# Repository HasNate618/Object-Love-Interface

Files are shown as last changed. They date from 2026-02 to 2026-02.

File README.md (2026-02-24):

# Object-Love-Interface 💘

> **🥇 Best Useless Hack** — CTRL+HACK+DEL 2.0 (York University)

What if you could go on a date with... literally any object?

Place an object in front of the camera. OLI scans it. Suddenly your bowl of ramen has a personality, a voice, opinions, and emotional availability. Using **Google Gemini API** to generate personalities and **ElevenLabs** to give them voices, we turned random objects into emotionally available Valentine's dates—all running on **Raspberry Pi** plus **three different ESP32 devices**.

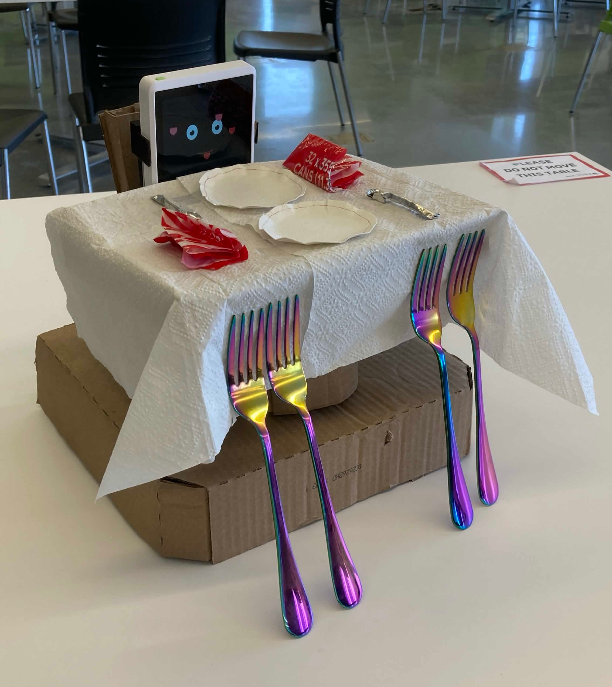
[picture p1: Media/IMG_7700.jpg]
Physical OLI Device


---

## 🏗️ System Architecture

A sophisticated multi-device IoT system bridging:
- **AI Generation** (Google Gemini 2.0 Flash) — personality description from image
- **Speech Synthesis** (ElevenLabs) — voices with emotion and character
- **Real-Time Display Sync** — synchronized animations across heterogeneous hardware

### Hardware Stack
| Device | Purpose | Interface | MCU |
|---|---|---|-----|
| **SenseCAP Indicator D1101** | Display + haptic feedback | USB Serial (921600 baud) | ESP32-S3 + RP2040 |
| **M5Stack Core** | WiFi audio speaker | HTTP (port 8082) | ESP32 |
| **Raspberry Pi 4/5** | Orchestrator brain | GPIO, USB, WiFi | ARM Cortex-A72 |
| **Brio Webcam** | Video + microphone input | USB | — |
| **Servo Motor** | Physical expression | GPIO serial | — |

### Software Stack

**Backend (Python 2440 LOC)**
- **OpenCV** — webcam capture (30 FPS video streaming)
- **PySerial** — USB serial protocol for SenseCAP (JPEG transfer, command/response)
- **PyAudio** — microphone input & voice recording
- **requests** — HTTP orchestration to Node.js server
- **google-generativeai** — Gemini API (personality generation)
- **pydub** — audio encoding/transcoding

**Frontend/Server (Node.js)**
- **Express.js** — HTTP API server (:3000)
- **@google/generative-ai** — Gemini 2.0 Flash for text generation
- **@elevenlabs/elevenlabs-js** — TTS voice synthesis with emotion
- **WebSocket (ws)** — real-time communication
- **multer** — file upload handling
- **dotenv** — environment secrets management

**Firmware (PlatformIO)**
- **ESP32-S3** — RGB LCD driver (ST7701S), JPEG decoding, touch input
- **RP2040** — buzzer control via UART, melody synthesis
- **ESP32** (M5Stack) — WiFi stack, ESP8266Audio library, internal DAC

---

## 🔄 Core Data Flow

### Image → Personality → Synchronized Playback (5-15s)

```
┌─ Webcam Frame (OpenCV, 30 FPS)
│
├─ Encode JPEG (Pillow)
│  └─ Send to SenseCAP display (USB serial, 921600 baud)
│
├─ Draw UI overlay (pink "Date ♥" button)
│
├─ Wait for button press (GPIO17 interrupt or SenseCAP touch)
│
├─ On trigger:
│  ├─ Save frame to disk
│  │
│  ├─ POST to Node.js: /generate-personality {image_b64}
│  │  └─ Google Gemini API (2-5s)
│  │     └─ Generate personality text + voice selection
│  │
│  ├─ ElevenLabs TTS synthesis (3-8s)
│  │  └─ Generate MP3 with emotion/character
│  │
│  ├─ Send face JPEG to SenseCAP (serial)
│  │
│  ├─ POST to M5Stack: /play {audio_url}
│  │  └─ M5 fetches MP3 via WiFi HTTP GET
│  │
│  ├─ mouth_sync.py: Poll M5 /status every 16ms
│  │  └─ Map audio position → mouth shape keyframe (0-8 frames)
│  │  └─ Resend JPEG with updated mouth to SenseCAP
│  │  └─ Stop at ~70% duration (character reaction)
│  │
│  └─ Return to video feed
```

### Voice Conversation Loop

```
Button Held (GPIO18 interrupt)
    ↓
Record microphone audio (PyAudio, 16-bit PCM @ device rate)
    ↓
Button Released
    ↓
Encode WAV → MP3 (pydub)
    ↓
POST to Node.js: /respond {audio_b64, context}
    ↓
Node:
  • Google Cloud Speech-to-Text (transcription)
  • Gemini API (contextual response using conversation history)
  • ElevenLabs TTS (emotion-aware voice synthesis)
  ↓
Python:
  • Fetch MP3 URL from response
  • POST to M5Stack: /play {audio_url}
  • mouth_sync.py: Sync mouth animation with audio
  • Update conversation context
  ↓
Return to video feed (ready for next interaction)
```

---

## 📁 Project Structure

```
Object-Love-Interface/
├── README.md (this file)
├── plan-rpiMigration.md          # Windows → Raspberry Pi migration guide
├── demo_script.md                # Demonstration walkthrough
│
├── Screen/                        # SenseCAP Indicator (ESP32-S3 + RP2040)
│   ├── esp32s3_firmware/         # PlatformIO: LCD driver + JPEG decoder
│   ├── rp2040_firmware/          # PlatformIO: Buzzer + melody control
│   └── controller/               # Python serial protocol library
│       ├── sensecap_controller.py  # Full serial API
│       ├── test_display.py        # RGB test pattern
│       ├── test_image.py          # JPEG encoding test
│       └── quick_test.py          # Integration test
│
├── Audio/                         # M5Stack Core (ESP32 WiFi Speaker)
│   ├── m5core2_firmware/         # PlatformIO: WiFi + audio DAC
│   │   ├── platformio.ini
│   │   └── src/main.cpp          # HTTP API + ESP8266Audio
│   └── README.md                 # HTTP API documentation
│
├── pipeline/                      # Main orchestrator (2440 LOC Python)
│   ├── date_pipeline.py          # (672 L) Video feed → button → personality
│   ├── conversation.py           # (495 L) Voice recording + AI responses
│   ├── mouth_sync.py             # (334 L) Audio position → mouth animation
│   ├── orchestrator.py           # (273 L) Multi-module coordination
│   ├── audio_server.py           # (189 L) Flask HTTP server
│   ├── gpio_button.py            # (140 L) GPIO interrupt handling
│   ├── wifi_link.py              # (215 L) WiFi TCP client for SenseCAP
│   ├── servo_serial.py           # (86 L) Servo motor control
│   ├── requirements.txt           # pip dependencies
│   └── README.md
│
├── image_to_voice/               # Node.js AI + TTS server
│   ├── index.js                  # Express server + Gemini + ElevenLabs
│   ├── package.json              # npm dependencies (express, generative-ai, elevenlabs)
│   ├── .env                      # API keys (gitignored)
│   ├── tmp/                      # Generated MP3 files (served over HTTP)
│   └── helper/                   # State management
│       ├── personality.js        # Personality persistence
│       ├── context.js            # Conversation history (multi-turn)
│       ├── interest.js           # Interest tracking
│       ├── voice.js              # Voice variant selection
│       └── dateStats.js          # Date interaction statistics
│
├── Media/                         # Test media files
│   └── IMG_7700.jpg              # Physical device photo
├── CAD/                           # Hardware designs
└── esp32_main/                   # Legacy ESP32 firmware
```

---

## ⚙️ Technical Implementation Details

### Serial Protocol (SenseCAP ↔ Raspberry Pi)

**Baud Rate**: 921600 (optimized for JPEG throughput)

**Command Format**: JSON-terminated newline, UTF-8 encoded

```json
// Image transfer (3-step handshake)
{"cmd":"image","len":65536}        // Announce size
[wait: {"status":"ready"}]         // Device ready
[send 65536 raw JPEG bytes]        // Binary image data
[wait: {"status":"ok"}]            // Transfer complete

// Buzzer control
{"cmd":"tone","freq":1000,"dur":500}        // Single tone
{"cmd":"melody","notes":"440:200,554:200"}  // Comma-separated freq:duration

// Display control
{"cmd":"clear","color":"#FF00FF"}   // Fill background
{"cmd":"bl","on":true}              // Backlight control
```

### HTTP API (Node.js Server)

**Base URL**: `http://<HOST_IP>:3000`

| Endpoint | Method | Input | Output | Latency |
|---|---|---|---|---|
| `/generate-personality` | POST | `{image_b64, camera_index}` | `{personality, voice_id, interest}` | 2-5s (Gemini) |
| `/respond` | POST | `{transcription, context}` | `{response, audio_url}` | 3-8s (TTS) |
| `/tmp/<filename>.mp3` | GET | — | MP3 audio stream | 0ms (file) |
| `/status` | GET | — | `{personality, voices, context_len}` | 0ms |

### Gemini API Integration

**Model**: `gemini-2.0-flash`

**Prompting Strategy**:
- Image base64 encoded + sent as multipart MIME
- System prompt establishes personality type
- Conversation context appended for multi-turn coherence
- Retry logic with exponential backoff (for 429 rate limits)

```javascript
// Example flow
const prompt = [
  {text: "You are a flirty object with opinions."},
  {inlineData: {mimeType: "image/jpeg", data: imageB64}},
  {text: "Describe yourself in 1-2 sentences."}
];
const response = await model.generateContent(prompt);
```

### ElevenLabs TTS Configuration

**Voice Model**: `elevenlabs-js` library

**Parameters**:
- Model: `eleven_turbo_v2` (fast, 500ms synthesis)
- Stability: 0.5 (balanced personality)
- Similarity boost: 0.75 (character consistency)
- Output format: MP3, 192 kbps

```javascript
const audio = await elevenlabs.generate({
  text: personality_description,
  voice_id: selected_voice,
  model_id: "eleven_turbo_v2"
});
```

### Mouth Sync Algorithm

**Keyframe System**: 9 mouth shapes (0-8 sprites)

**Timing**: Poll M5 `/status` at 16ms intervals (60 FPS target)

```python
# mouth_sync.py logic
audio_position_ms = elapsed_time * 1000
audio_duration_ms = total_duration * 1000

# Stop at 70% for reaction time
cutoff_position = audio_duration_ms * 0.7

mouth_frame = 0
if audio_position_ms < cutoff_position:
    # Map position to mouth shape (0-8)
    mouth_frame = int((audio_position_ms / cutoff_position) * 8)

# Resend JPEG with updated mouth to SenseCAP
send_face_jpeg(mouth_frame)
```

### GPIO Interrupt Handling

**GPIO Pins** (Raspberry Pi):
- **GPIO17**: Date button (primary)
- **GPIO18**: Voice recording (optional)
- **GPIO38**: Limit switch (emergency restart)

**Edge Detection**: Rising edge + debounce (10ms)

```python
# gpio_button.py
def setup_button(pin, callback):
    GPIO.setmode(GPIO.BCM)
    GPIO.setup(pin, GPIO.IN, pull_up_down=GPIO.PUD_UP)
    GPIO.add_event_detect(pin, GPIO.RISING, 
                         callback=callback, bouncetime=10)
```

### Camera Detection (RPi USB)

**Supported**: 
- USB cameras (via `/dev/video*`)
- CSI ribbon cameras
- Brio webcam (UVC)

**Detection**:
```bash
# v4l2 enumeration
v4l2-ctl --list-devices

# OpenCV fallback (auto-select index 0-5)
python find_camera.py
```

---

## 🚀 Quick Start

### Prerequisites
- **Raspberry Pi 4/5** (or Windows laptop for testing)
- **Node.js 18+**
- **Python 3.8+**
- **PlatformIO CLI** (for firmware flashing)
- **ffmpeg** (audio transcoding)

### Setup

```bash
# 1. Clone and install dependencies
git clone https://github.com/HasNate618/Object-Love-Interface.git
cd Object-Love-Interface

# 2. Python environment
pip install -r pipeline/requirements.txt

# 3. Node environment
cd image_to_voice
npm install
cp .env.example .env  # Add GEMINI_API_KEY, ELEVENLABS_API_KEY
cd ..

# 4. Flash firmware (first time only)
cd Screen/esp32s3_firmware && pio run --target upload && cd ../..
cd Screen/rp2040_firmware && pio run --target upload && cd ../..
cd Audio/m5core2_firmware && pio run --target upload && cd ../..

# 5. Update .env for your network
# Edit image_to_voice/.env: set HOST_IP to your RPi IP
# Edit pipeline/config: set SENSECAP_PORT to /dev/ttyUSB0 (RPi) or COM6 (Windows)

# 6. Start services
# Terminal 1:
cd image_to_voice && npm start

# Terminal 2:
cd pipeline && python date_pipeline.py --port /dev/ttyUSB0 --camera 0
```

### Testing Individual Components

```bash
# Test webcam detection
python find_camera.py

# Test SenseCAP serial communication
cd Screen/controller && python test_image.py /dev/ttyUSB0

# Test M5Stack WiFi playback
python test_backends.py

# Test full integration
python pipeline/date_pipeline.py --verbose
```

---

## 🔧 Configuration

### Environment Variables (`.env`)

```bash
# API Keys (REQUIRED)
GEMINI_API_KEY="..."
ELEVENLABS_API_KEY="..."

# Network (UPDATE FOR YOUR SETUP)
HOST_IP=10.216.64.XXX           # Raspberry Pi LAN address
M5CORE2_URL=http://10.216.64.147:8082/play
M5_PLAY_URL=http://10.216.64.147:8082/play

# Server
IMAGE_TO_VOICE_URL=http://localhost:3000
PORT=3000

# Optional
DISABLE_ROBOT_TTS=0
MIC_NAME="Brio"
DATE_CAMERA_INDEX=0
```

---

## 📊 Performance Metrics

| Operation | Duration | Bottleneck |
|---|---|---|
| Webcam capture + JPEG encode | 80-150ms | PIL libjpeg-turbo |
| Gemini API call | 2-5s | Network + model inference |
| ElevenLabs TTS | 3-8s | API latency |
| USB serial JPEG transfer (65KB) | 200-500ms | 921600 baud (~115 KB/s) |
| Mouth sync loop | 16ms/frame | HTTP polling to M5 |
| **Full interaction cycle** (button→speech) | **5-15s** | Gemini + ElevenLabs |

---

## 🛠️ Migration Guide

See [plan-rpiMigration.md](plan-rpiMigration.md) for detailed steps to migrate from Windows laptop to Raspberry Pi, including:
- Serial port remapping (COM6 → `/dev/ttyUSB0`)
- Network configuration (HOST_IP in `.env`)
- Hardware USB reallocation
- Troubleshooting common issues

---

## 🏆 Project Origins

**Built at**: CTRL+HACK+DEL 2.0 (York University Hackathon)  
**Duration**: 36 hours  
**Team**: 3 developers  
**Award**: 🥇 Best Useless Hack  
**Prize**: Iridescent forks (now displayed proudly)

This project perfectly demonstrates the power of combining cutting-edge APIs (Gemini, ElevenLabs) with embedded systems (Raspberry Pi, ESP32 ecosystem) to create something simultaneously useless and technically impressive.

---

## 📚 Further Reading

- [SenseCAP Indicator Hardware](Screen/README.md) — Display firmware + serial protocol
- [M5Stack Audio Server](Audio/README.md) — WiFi speaker control
- [Python Pipeline](pipeline/README.md) — Orchestration details
- [Demo Script](demo_script.md) — Walkthrough of a typical interaction
- [RPi Migration Plan](plan-rpiMigration.md) — Deployment instructions

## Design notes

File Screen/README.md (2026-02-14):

# SenseCAP Indicator Display + Buzzer Control

Control the SenseCAP Indicator D1101 display and buzzer in real time from a Raspberry Pi (or any host) via USB serial.

## Architecture

```
┌──────────────┐     USB Serial     ┌──────────────────────────────────────┐
│  Raspberry Pi│◄──────────────────►│  SenseCAP Indicator                  │
│  (or PC)     │   JSON commands    │  ┌──────────┐    UART   ┌─────────┐ │
│              │                    │  │ ESP32-S3 │◄────────►│ RP2040  │ │
│  Python      │                    │  │ (Display)│           │ (Buzzer)│ │
│  Controller  │                    │  └──────────┘           └─────────┘ │tt
└──────────────┘                    └──────────────────────────────────────┘
```

- **ESP32-S3**: Drives the 4" 480x480 LCD via direct RGB panel, decodes JPEGs
- **RP2040**: Controls the built-in buzzer, receives commands via internal UART
- **Python Controller**: Sends JSON commands and JPEGs over USB serial

## Project Structure

```
Screen/
├── esp32s3_firmware/      # PlatformIO project for ESP32-S3 (display)
├── rp2040_firmware/       # PlatformIO project for RP2040 (buzzer)
├── controller/            # Python scripts for host control
│   ├── sensecap_controller.py   # Controller API library
│   ├── test_display.py          # RGB color cycle test
│   ├── test_image.py            # JPEG test pattern
│   └── quick_test.py            # Short smoke test
└── README.md
```

## Setup

### Prerequisites
- [PlatformIO](https://platformio.org/) (CLI or VS Code extension)
- Python 3.8+ with `pyserial`
- USB-C cable

### 1. Flash RP2040 Firmware (Buzzer)
```bash
cd Screen/rp2040_firmware
pio run --target upload
```
**Note:** To enter RP2040 bootloader mode, hold the BOOT button while pressing RESET on the SenseCAP Indicator.

### 2. Flash ESP32-S3 Firmware (Display)
```bash
cd Screen/esp32s3_firmware
pio run --target upload
```
**Note:** To enter ESP32-S3 download mode, hold the BOOT button while pressing RESET. The ESP32-S3 appears as a separate COM port from the RP2040.

### 3. Install Python Dependencies
```bash
cd Screen/controller
pip install -r requirements.txt
```

### 4. Run a Test Script
```bash
python test_display.py COM6           # Windows - use your actual port
python test_image.py /dev/ttyACM0     # Linux/Pi
```

## Serial Protocol

Commands are JSON objects terminated by `\n`. Each command receives a JSON response.

### Commands

| Command | Parameters | Description |
|---|---|---|
| `image` | `len` | Start JPEG transfer (bytes). Device replies `{"status":"ready"}` before raw bytes are sent. |
| `clear` | `color` | Fill screen with background color (hex). |
| `tone` | `freq, dur` | Play buzzer tone (Hz, ms) via RP2040. |
| `melody` | `notes` | Play comma-separated `freq:dur` pairs. |
| `stop` | - | Stop buzzer. |
| `bl` | `on` | Backlight control (true/false). |

### JPEG Transfer Flow

1. Send header command:
```json
{"cmd":"image","len":123456}
```
2. Wait for:
```json
{"status":"ready"}
```
3. Send raw JPEG bytes.
4. Device responds:
```json
{"status":"ok"}
```

### Example Commands
```json
{"cmd":"clear","color":"#000000"}
{"cmd":"tone","freq":1000,"dur":500}
{"cmd":"melody","notes":"440:200,554:200,659:400"}
{"cmd":"bl","on":true}
```

### Response Format
```json
{"status":"ok"}
{"status":"error","msg":"unknown command"}
{"status":"ready"}
```

## Pin Reference (SenseCAP Indicator D1101)

### ESP32-S3 GPIOs (from official Seeed SDK)
| Function | GPIO | Notes |
|---|---|---|
| I2C SDA | 39 | Shared with TCA9535 + touch |
| I2C SCL | 40 | Shared with TCA9535 + touch |
| LCD SPI CLK | 41 | 3-wire SPI for ST7701S init |
| LCD SPI MOSI | 48 | 3-wire SPI for ST7701S init |
| LCD VSYNC | 17 | RGB panel |
| LCD HSYNC | 16 | RGB panel |
| LCD DE | 18 | RGB panel |
| LCD PCLK | 21 | 18 MHz pixel clock |
| LCD Backlight | 45 | Active HIGH |
| RGB Data D0..D15 | 15..0 | RGB565 mapping |
| UART TX (→RP2040) | 19 | Internal UART |
| UART RX (←RP2040) | 20 | Internal UART |

### RP2040 GPIOs
| Function | GPIO |
|---|---|
| Buzzer | 19 |
| UART TX (→ESP32) | 20 |
| UART RX (←ESP32) | 21 |

## Troubleshooting

- **No display**: Verify ST7701S init and pin mapping in `pins.h`.
- **Garbled colors**: Check RGB timing parameters in `display.cpp`.
- **No serial response**: Ensure you are on the ESP32-S3 COM port (CH340).
- **No buzzer**: Flash RP2040 firmware separately and confirm UART wiring.

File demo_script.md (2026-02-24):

# Object Love Interface - Hackathon Demo Script (Valentines)

Length: 2-3 minutes
Tone: absurdist/chaotic, but clear on tech value

## Cast
- Host: you
- Device: SenseCAP screen + M5 speaker voice
- Object: any small item you can hold up to the camera (recommend: stapler, mug, keyboard, or a banana)

## Stage Setup
- SenseCAP screen facing judges
- M5 speaker audible
- Camera pointed at object
- Servo arm visible if possible
- Fallback: prerecorded clip ready to play

## Run of Show (Quick)
1. Cold open and premise
2. Live capture + Date button
3. Object speaks (Gemini + ElevenLabs)
4. Short back-and-forth (push-to-talk)
5. Servo gag and hearts
6. Callouts: Valentines track + Gemini + ElevenLabs
7. Optional: quick fallback line if live capture fails

## Script

### 0:00 - Cold open
Host:
"Judges, today we are putting romance on hard mode. We built a device that lets you date any object. This is Object Love Interface."

Host:
"It uses a camera, Gemini to imagine a personality, and ElevenLabs to give it a voice. The screen shows faces and hearts, and the servo arm reacts to chemistry."

### 0:20 - Pick the date
Host (holding object to camera):
"Meet my date: this [OBJECT]. The internet told me not to do this, but the AI told me it is destiny."

Host (point to SenseCAP screen):
"I am going to hit Date."

### 0:25 - Live capture + personality generation
Stage direction:
- Tap the Date button on the SenseCAP screen.
- Device shows face mode and hearts.

Host (while it thinks):
"Camera capture goes in, Gemini describes it, then Gemini writes a full dating personality profile."

### 0:35 - Object speaks first
Device (ElevenLabs voice):
"Hi. I am [OBJECT NAME]. I am small, underestimated, and ready for a serious relationship with a human."

Host:
"The voice is ElevenLabs, streamed over WiFi to the M5 speaker. Mouth sync on the face is driven by audio amplitude."

### 0:50 - Short back-and-forth (push-to-talk)
Host (hold button, speak):
"So what are you looking for in a partner?"

Device:
"Someone who respects my personal space. Also, I am very into long walks on short shelves."

Stage direction:
- Servo arm does a small move on a good response.
- Screen shows hearts or a happy face.

Host:
"You can see the system updating the love meter and the servo reacts to how the date is going."

### 1:20 - Another quick exchange
Host (hold button, speak):
"What is your love language?"

Device:
"Acts of service. Specifically, cleaning me and never putting me in the top rack."

Host:
"That is dangerously relatable."

### 1:35 - Valentines track callout
Host:
"We are aiming for the Valentines prize track. This is a romance engine for objects."

Host:
"And for Best Use of Gemini and ElevenLabs: Gemini creates the personality and dialogue, ElevenLabs gives it an emotional voice, and our hardware brings it to life in real time."

### 1:55 - Closing beat
Host:
"So yes, you can now date your stapler. Do not judge me, judge the architecture."

Host:
"Object Love Interface. Please clap so my date does not ghost me."

## Fallback (if live demo fails)
Host:
"If the live capture is shy, here is a quick clip of the full flow. Same pipeline, just pre-recorded."

Stage direction:
- Play the short clip (15-25 seconds) of capture -> personality -> voice -> hearts -> servo.

## Notes for Timing
- Keep each device response under 1 sentence.
- If the system is slow, add one line: "Gemini is cooking a personality profile right now." 
- If audio is quiet, do a quick volume bump using the M5 control.

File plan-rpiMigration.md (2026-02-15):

# Plan: Full Migration to Raspberry Pi

**Summary**: Migrate the complete Object-Love-Interface system from Windows laptop to Raspberry Pi. This includes the Node.js server (image_to_voice), Python pipeline scripts, and all connected hardware (Brio webcam with mic, SenseCAP Indicator via USB). Only the M5Core1 audio player remains on WiFi at its current IP. The primary change is updating `HOST_IP` in .env to the RPi's DHCP address and changing all serial port references from `COM6` to `/dev/ttyUSB0` or `/dev/ttyACM0`. This consolidates everything on one device, eliminating cross-machine HTTP calls and simplifying the deployment.

**Decision**: Full migration chosen over partial migration because keeping Python on Windows while moving Node to RPi would create audio file serving complexity (M5 fetching from RPi but Python generating on Windows).

## Steps

1. **Prepare RPi System**
   - Install Node.js 18+: `curl -fsSL https://deb.nodesource.com/setup_18.x | sudo -E bash - && sudo apt-get install nodejs`
   - Install Python 3.8+ (usually pre-installed): `python3 --version`
   - Install system dependencies: `sudo apt-get update && sudo apt-get install -y ffmpeg python3-pip git`
   - Add user to dialout group for serial access: `sudo usermod -a -G dialout $USER` then logout/login or reboot

2. **Transfer Project Files**
   - Copy entire project to RPi using git: `git clone <repo_url>` OR rsync from Windows: `rsync -avz /path/to/Object-Love-Interface/ pi@<rpi_ip>:~/Object-Love-Interface/`
   - Copy .env file (contains API keys): Manually transfer since it's gitignored
   - Verify all files present: `ls -la ~/Object-Love-Interface/`

3. **Install Dependencies**
   - Node packages: `cd ~/Object-Love-Interface/image_to_voice && npm install`
   - Python packages: `cd ~/Object-Love-Interface && pip3 install -r pipeline/requirements.txt`
   - Test ffmpeg: `ffmpeg -version` (should show version from 2014+)

4. **Configure Network Settings**
   - Find RPi IP: `hostname -I` (first IP is LAN address, e.g., `10.216.64.XXX`)
   - Edit .env line 9: Change `HOST_IP=10.216.64.90` to `HOST_IP=<RPi_IP_from_above>`
   - Keep other values: `M5CORE2_URL=http://10.216.64.147:8082/play` unchanged (M5 stays at same IP)
   - Verify: `cat image_to_voice/.env | grep HOST_IP`

5. **Connect Hardware to RPi**
   - Unplug Brio webcam from Windows, connect to RPi USB port
   - Unplug SenseCAP Indicator USB from Windows (COM6), connect to RPi USB port
   - Wait 5 seconds for devices to enumerate
   - Check serial ports: `ls -l /dev/tty* | grep USB` (look for `/dev/ttyUSB0` or `/dev/ttyACM0`)
   - Test webcam: `python3 -c "import cv2; cap=cv2.VideoCapture(0); print('Camera OK' if cap.isOpened() else 'FAIL')"`
   - Test mic: `python3 -c "import pyaudio; pa=pyaudio.PyAudio(); print([pa.get_device_info_by_index(i)['name'] for i in range(pa.get_device_count())])"`

6. **Update Python Script Defaults** (Optional - can use command-line args instead)
   - conversation.py line 365: Change default `port="COM6"` to `port="/dev/ttyUSB0"` if desired
   - date_pipeline.py line 463: Change default `"COM6"` to `"/dev/ttyUSB0"` if desired
   - OR always pass `--port /dev/ttyUSB0` when running scripts (recommended for flexibility)

7. **Test Node.js Server**
   - Start server: `cd ~/Object-Love-Interface/image_to_voice && node index.js`
   - Verify console output shows: `Detected LAN IP: <RPi_IP>`, `Listening on 0.0.0.0:3000`
   - Check audio host URL matches RPi IP: Should show `http://<RPi_IP>:3000`
   - Test from Windows browser: `http://<RPi_IP>:3000` (should see "image_to_voice server")
   - Leave running in terminal for integration test

8. **Test Python Pipeline**
   - Open new SSH session or terminal tab on RPi
   - Run date pipeline: `cd ~/Object-Love-Interface && python3 pipeline/date_pipeline.py --port /dev/ttyUSB0 --camera 0 --server http://localhost:3000`
   - Verify SenseCAP display shows webcam feed
   - Press physical "Date ♥" button on SenseCAP
   - Check for: Image capture → personality generation → TTS audio → M5 playback → face display → mouth sync
   - Monitor Node terminal for: POST /generate-personality, TTS generation, audio file creation

9. **Test Voice Conversation**
   - In Python terminal, hold SenseCAP button to record voice
   - Release button, verify: STT transcription → POST /respond → TTS generation → M5 playback + mouth sync
   - Check timing: Mouth animation should stop ~0.7x through audio playback
   - Test multiple interactions to verify stability

10. **Network Verification from M5 Perspective**
    - Confirm M5Core1 can reach RPi: From another device on `espTest` WiFi, test `curl http://<RPi_IP>:3000/tmp/` 
    - Check M5 serial monitor (if accessible): Should show successful HTTP GET for audio files
    - If M5 restarts or fails to play: Check WiFi routing, ensure RPi and M5 on same subnet or routable networks

## Verification

- **Functionality tests**:
  - Capture image → personality generation completes in <10s
  - TTS audio files appear in `~/Object-Love-Interface/image_to_voice/tmp/` directory
  - M5Core1 plays audio clearly without restarts
  - Mouth animation syncs with audio and stops at ~70% of audio duration
  - Recording voice → STT → AI response cycle works end-to-end
  
- **Debug commands**:
  - Check serial port: `python3 -m serial.tools.list_ports`
  - List cameras: `v4l2-ctl --list-devices` or `ls /dev/video*`
  - Test Node API: `curl http://localhost:3000` from RPi
  - Monitor M5 connectivity: `ping 10.216.64.147` from RPi
  - Check audio files: `ls -lh ~/Object-Love-Interface/image_to_voice/tmp/`

- **Error checking**:
  - If "ENOENT ./tmp/" error: Node should auto-create, check file permissions with `ls -ld image_to_voice/tmp/`
  - If M5 doesn't play: Check Node console for POST /play response status code
  - If mouth doesn't move: Check Python console for `[mouth_sync]` debug output
  - If camera fails: Try `--camera 1` or check `DATE_CAMERA_INDEX` environment variable
  - If mic not found: Check `pyaudio.PyAudio().get_device_count()` and adjust `MIC_NAME` pattern

## Decisions

- **Chose full migration over partial**: Moving only Node.js would require Python to generate files on Windows but M5 to fetch from RPi, creating unnecessary network complexity and latency
- **Using command-line args for serial port**: Rather than hardcoding `/dev/ttyUSB0` in Python files, pass `--port` argument for flexibility (device name may vary as ttyUSB0 vs ttyACM0)
- **Keeping localhost for Python→Node**: Since both run on RPi, Python can use `http://localhost:3000` instead of RPi IP (reduces config complexity)
- **No systemd autostart initially**: Manual start gives flexibility for debugging; can add systemd services later if stable
- **DHCP acceptable for testing**: Static IP recommended for production but DHCP sufficient for initial migration; HOST_IP in .env can be updated later if IP changes

---

## Architecture Overview

### Current State (Windows Laptop)
- **Windows Laptop (10.216.64.90)**
  - Node.js server on port 3000
  - Python pipeline scripts
  - Brio webcam (USB) for video + microphone
  - SenseCAP Indicator (COM6 USB serial) for display + buttons
- **M5Core1 (10.216.64.147:8082)**
  - Audio player firmware
  - Fetches MP3 from laptop via HTTP
- **Network**: All on WiFi "espTest"

### Target State (Raspberry Pi)
- **Raspberry Pi (<DHCP_IP>)**
  - Node.js server on port 3000
  - Python pipeline scripts
  - Brio webcam (USB) for video + microphone
  - SenseCAP Indicator (/dev/ttyUSB0) for display + buttons
- **M5Core1 (10.216.64.147:8082)**
  - No changes to firmware
  - Fetches MP3 from RPi instead
- **Network**: All on WiFi "espTest"

### Communication Flows After Migration
```
┌─────────────────────────────────────────┐
│         Raspberry Pi (<RPi_IP>)         │
│  ┌──────────┐        ┌──────────────┐  │
│  │ Node.js  │◄───────┤ Python       │  │
│  │ :3000    │ HTTP   │ - capture    │  │
│  │          │        │ - STT        │  │
│  │ Serves   │        │ - mouth_sync │  │
│  │ /tmp/*.  │        └──────┬───────┘  │
│  │ mp3      │               │          │
│  └────┬─────┘               │          │
│       │                     │          │
│       │ POST /play          │ Serial   │
│       │ {url:audio}         │ USB      │
│       ▼                     ▼          │
└───────┼─────────────────────┼──────────┘
        │                     │
        │ WiFi                │ USB
        ▼                     ▼
  ┌──────────┐    ┌───────────────────┐
  │ M5Core1  │    │ SenseCAP Display  │
  │ :8082    │    │ /dev/ttyUSB0      │
  │          │    │                   │
  │ HTTP GET │    │ LCD + Touch       │
  │ MP3 from │    │ Button Events     │
  │ RPi      │    │ Mouth Animation   │
  └──────────┘    └───────────────────┘
```

---

## Files Requiring Updates

### Critical Changes

**image_to_voice/.env** (Line 9)
```diff
- HOST_IP=10.216.64.90
+ HOST_IP=<RPi_IP>
```

### Optional Changes (Can use CLI args instead)

**pipeline/conversation.py** (Line 365)
```diff
- def main(port="COM6", mic_device=None, server_url=None):
+ def main(port="/dev/ttyUSB0", mic_device=None, server_url=None):
```

**pipeline/date_pipeline.py** (Line 463)
```diff
- parser.add_argument("--port", default="COM6", help="SenseCAP serial port")
+ parser.add_argument("--port", default="/dev/ttyUSB0", help="SenseCAP serial port")
```

**Alternative**: Always use `--port /dev/ttyUSB0` in commands (recommended)

---

## Rollback Procedure

If migration fails or needs to revert:

1. Stop all services on RPi (Ctrl+C in terminals)
2. Disconnect Brio webcam from RPi, reconnect to Windows
3. Disconnect SenseCAP from RPi, reconnect to Windows (COM6)
4. On Windows: Edit `.env` line 9 back to `HOST_IP=10.216.64.90`
5. On Windows: Restart Node server: `cd image_to_voice && node index.js`
6. On Windows: Run Python: `python pipeline/date_pipeline.py --port COM6 --camera 1 --server http://localhost:3000`
7. System returns to original working state

**No changes to M5Core1 firmware required for rollback.**

---

## Troubleshooting Guide

### Serial Port Issues
- **Symptom**: "Permission denied" on `/dev/ttyUSB0`
- **Fix**: Add user to dialout group: `sudo usermod -a -G dialout $USER` then logout/login
- **Alt Fix**: Run with sudo (not recommended for production)

### Camera Not Found
- **Symptom**: `cv2.VideoCapture(0).isOpened()` returns False
- **Fix**: Try different index: `--camera 1` or `--camera 2`
- **Check**: `v4l2-ctl --list-devices` to see available cameras
- **Set env**: `export DATE_CAMERA_INDEX=1` if needed

### Microphone Not Detected
- **Symptom**: "No external mic found" warning
- **Fix**: List devices: `python3 -c "import pyaudio; pa=pyaudio.PyAudio(); [print(i, pa.get_device_info_by_index(i)) for i in range(pa.get_device_count())]"`
- **Update**: Set `MIC_NAME` env var to match device name pattern

### M5 Cannot Reach RPi
- **Symptom**: M5Core1 restarts or audio doesn't play
- **Check**: From device on espTest WiFi: `curl http://<RPi_IP>:3000/`
- **Fix**: Ensure RPi on same subnet or routable network
- **Debug**: Check RPi firewall: `sudo ufw status` (disable if needed for testing)

### ffmpeg Errors
- **Symptom**: "Decoding failed. ffmpeg returned error code: 1"
- **Fix**: Install ffmpeg: `sudo apt-get install ffmpeg`
- **Check**: `which ffmpeg` should return `/usr/bin/ffmpeg`

### Node Server Won't Start
- **Symptom**: Port 3000 already in use
- **Fix**: Kill existing process: `sudo lsof -ti:3000 | xargs kill -9`
- **Alt Port**: Set `PORT=3001` in .env

### TTS Files Not Created
- **Symptom**: "ENOENT: no such file or directory './tmp/audio_*.mp3'"
- **Fix**: Node should auto-create, check: `ls -ld ~/Object-Love-Interface/image_to_voice/tmp/`
- **Manual**: `mkdir -p ~/Object-Love-Interface/image_to_voice/tmp`

---

## Environment Variables Reference

### Node.js (.env file)
```bash
# API Keys (copy from Windows)
GEMINI_API_KEY="..."
ELEVENLABS_API_KEY="..."

# Network (UPDATE THIS)
HOST_IP=<RPi_IP>              # ← REQUIRED CHANGE

# M5Core1 (no change)
M5CORE2_URL=http://10.216.64.147:8082/play
M5_PLAY_URL=http://10.216.64.147:8082/play

# Server (no change)
IMAGE_TO_VOICE_URL="http://localhost:3000"
PORT=3000
```

### Python (shell exports - optional)
```bash
# If not using command-line args
export IMAGE_TO_VOICE_URL="http://localhost:3000"  # Same machine
export M5_PLAY_URL="http://10.216.64.147:8082/play"
export SENSECAP_PORT="/dev/ttyUSB0"
export DATE_CAMERA_INDEX=0
export MIC_NAME="Brio"  # Or pattern from pyaudio device list
```

---

## Post-Migration Validation Checklist

- [ ] RPi Node server starts without errors
- [ ] Console shows correct RPi IP address
- [ ] Windows can access `http://<RPi_IP>:3000` via browser
- [ ] SenseCAP displays webcam feed when Python runs
- [ ] Pressing Date button triggers image capture
- [ ] Gemini personality generation completes
- [ ] TTS audio file appears in tmp/ directory
- [ ] M5Core1 plays audio without restarting
- [ ] SenseCAP face animation displays correctly
- [ ] Mouth sync animation matches audio timing
- [ ] Button hold records voice successfully
- [ ] STT transcription appears in console
- [ ] AI response generates and speaks
- [ ] Full conversation loop works end-to-end
- [ ] System stable after 5+ interaction cycles

---

## Future Enhancements (Post-Migration)

### Systemd Services (if auto-start desired)

**Node.js Service**: `/etc/systemd/system/image-to-voice.service`
```ini
[Unit]
Description=Image to Voice Node Server
After=network.target

[Service]
Type=simple
User=pi
WorkingDirectory=/home/pi/Object-Love-Interface/image_to_voice
EnvironmentFile=/home/pi/Object-Love-Interface/image_to_voice/.env
ExecStart=/usr/bin/node index.js
Restart=on-failure
RestartSec=10

[Install]
WantedBy=multi-user.target
```

**Python Pipeline Service**: `/etc/systemd/system/date-pipeline.service`
```ini
[Unit]
Description=Date Pipeline
After=network.target image-to-voice.service
Requires=image-to-voice.service

[Service]
Type=simple
User=pi
WorkingDirectory=/home/pi/Object-Love-Interface
ExecStart=/usr/bin/python3 pipeline/date_pipeline.py --port /dev/ttyUSB0 --camera 0 --server http://localhost:3000
Restart=on-failure
RestartSec=10

[Install]
WantedBy=multi-user.target
```

Enable services:
```bash
sudo systemctl daemon-reload
sudo systemctl enable image-to-voice
sudo systemctl enable date-pipeline
sudo systemctl start image-to-voice
sudo systemctl start date-pipeline
```

### Static IP Configuration
If DHCP causes issues, assign static IP in `/etc/dhcpcd.conf`:
```
interface wlan0
static ip_address=10.216.64.XX/24
static routers=10.216.64.1
static domain_name_servers=8.8.8.8
```

### Performance Monitoring
```bash
# CPU/Memory usage
htop

# Network traffic
sudo iftop -i wlan0

# Service logs
sudo journalctl -u image-to-voice -f
sudo journalctl -u date-pipeline -f
```

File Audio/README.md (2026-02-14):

# M5Stack Core Audio (WiFi Speaker)

This component runs on an M5Stack Core (gen1, ESP32) and exposes a small HTTP API for playing audio URLs over WiFi. It uses ESP8266Audio to decode MP3/WAV and outputs through the Core1 internal DAC (GPIO25/26).

## Hardware

- Device: M5Stack Core (gen1)
- Output: Internal DAC speaker path
- Network: WiFi (HTTP control)

## Firmware Layout

```
Audio/
├── m5core2_firmware/   # PlatformIO project (Core1-targeted)
│   ├── platformio.ini
│   └── src/
│       ├── main.cpp
│       └── wifi_config.h
└── README.md
```

## Build + Flash

1. Edit WiFi credentials in [Audio/m5core2_firmware/src/wifi_config.h](m5core2_firmware/src/wifi_config.h).
2. Flash from PlatformIO:

```bash
cd Audio/m5core2_firmware
pio run --target upload --upload-port COM9
```

## HTTP API

The device listens on port 8082 (configurable in `wifi_config.h`).

### POST /play
Play an audio URL.

```json
{"url":"http://host:8080/audio/file.mp3","format":"mp3"}
```

### POST /stop
Stop playback.

### POST /volume
Set volume on a 0-10 scale.

```json
{"level":10}
```

### POST /tone
Simple speaker test (useful to verify audio path).

```json
{"freq":880,"duration":800}
```

### GET /status
Returns playback state and current URL.

```json
{"playing":true,"volume":10,"url":"http://...","ip":"10.x.x.x"}
```

## Notes

- The folder name is historical (`m5core2_firmware`), but the build targets Core1 hardware.
- Output uses `AudioOutputI2S(INTERNAL_DAC)` for Core1 speaker audio.
- `/play` is non-blocking; playback starts in the main loop to avoid HTTP timeouts.

## Quick Test

1. Start a local HTTP server in the Media folder:

```bash
cd Media
python -m http.server 8080
```

2. Trigger playback:

```python
import requests
requests.post("http://<core_ip>:8082/play", json={
    "url": "http://<host_ip>:8080/kittenstrike1-quothello-therequot-158832.mp3",
    "format": "mp3",
})
```

3. Use `/tone` if you only want to verify speaker output.

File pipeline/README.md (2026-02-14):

# Pipeline (Camera -> Gemini -> ElevenLabs -> Display + Audio)

This folder contains the host-side pipeline that captures a camera frame, sends it to Gemini for a caption, generates speech via ElevenLabs, then plays the audio on the M5Stack Core speaker and shows the image on the SenseCAP display.

## Components

- [pipeline/orchestrator.py](orchestrator.py)
  - Captures a webcam frame (OpenCV)
  - Sends image + prompt to Gemini
  - Converts response to speech via ElevenLabs
  - Sends image to SenseCAP (serial)
  - Sends audio to M5Stack via the audio server

- [pipeline/audio_server.py](audio_server.py)
  - Flask server that stores audio files and serves them to the M5Stack
  - Convenience endpoint `/upload_and_play` for the orchestrator

- [pipeline/requirements.txt](requirements.txt)
  - Python dependencies for the pipeline

## Environment Variables

Set these before running:

- `GEMINI_API_KEY`
- `ELEVENLABS_API_KEY`
- `ELEVENLABS_VOICE_ID` (optional, default Rachel)
- `M5CORE2_IP` (Core1 IP address; name kept for compatibility)
- `SENSECAP_PORT` (default `COM6` or `/dev/ttyUSB0`)
- `AUDIO_SERVER_URL` (default `http://localhost:8080`)
- `GEMINI_MODEL` (default `gemini-2.0-flash`)

## Install

```bash
pip install -r pipeline/requirements.txt
```

## Run Audio Server

```bash
python pipeline/audio_server.py
```

The server listens on port 8080 and stores audio files in `pipeline/audio_files/`.

## Run Orchestrator

Single run:

```bash
python pipeline/orchestrator.py --once
```

Continuous loop:

```bash
python pipeline/orchestrator.py --loop --interval 10
```

## Network Notes

- The M5Stack must be able to reach the host machine running `audio_server.py`.
- `audio_server.py` auto-detects the host LAN IP when serving audio URLs.
- If the M5Stack is on a different subnet, use a reachable host IP and adjust firewall rules.

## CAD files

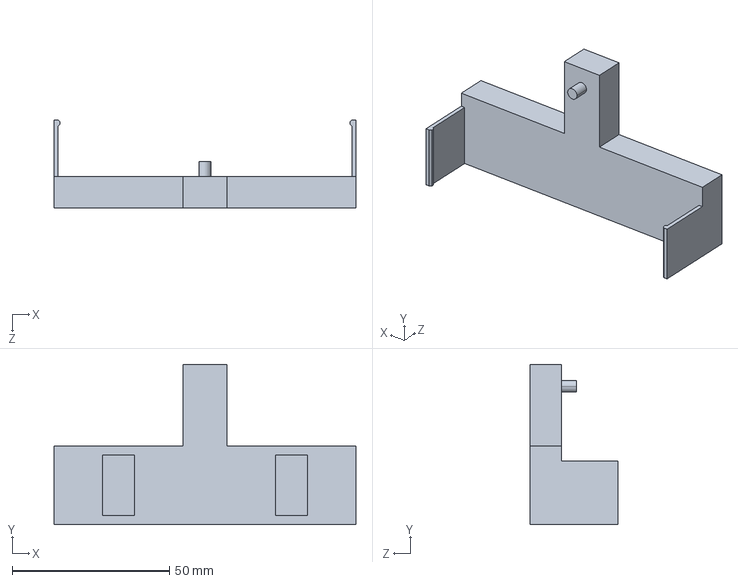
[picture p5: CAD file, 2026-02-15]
CAD/Export/SnapClip.STEP
96.0 x 51.0 x 28.0 mm

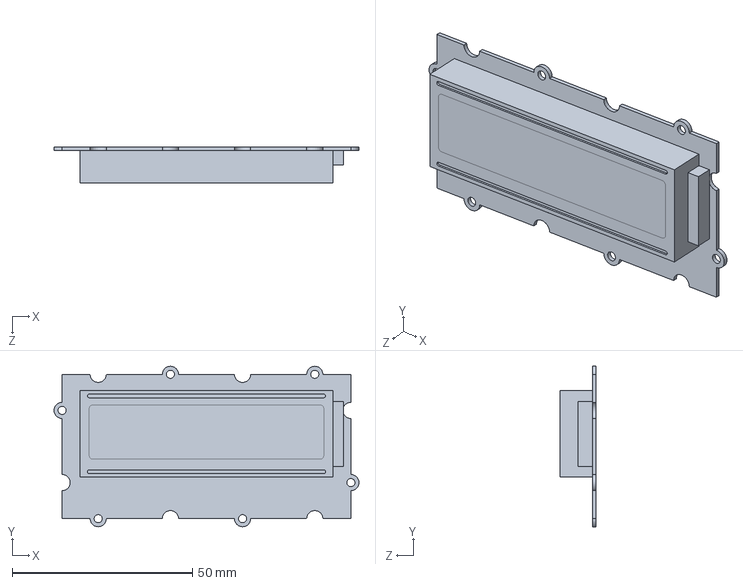
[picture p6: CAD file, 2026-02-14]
CAD/Imported/grove-lcd-rgb-backlight-1.snapshot.6/Grove-LCD RGB Backlight/LCD RGB Backlight.SLDPRT
84.5 x 44.5 x 10.0 mm

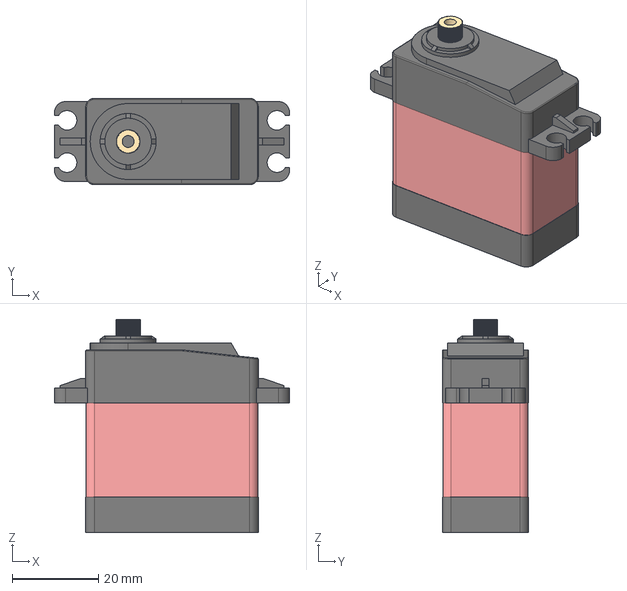
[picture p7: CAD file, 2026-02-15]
CAD/Imported/td-8135mg-35kg-servo-1.snapshot.2/TD-8135MG Servo v5.step
54.4 x 20.0 x 49.4 mm

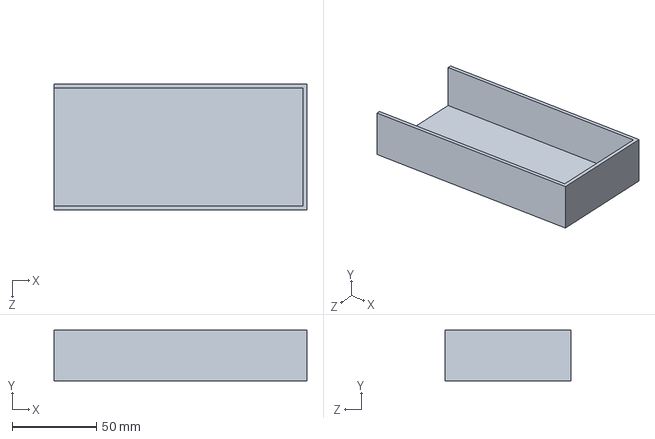
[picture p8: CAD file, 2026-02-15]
CAD/TableContainer.SLDPRT
150.0 x 30.0 x 75.0 mm

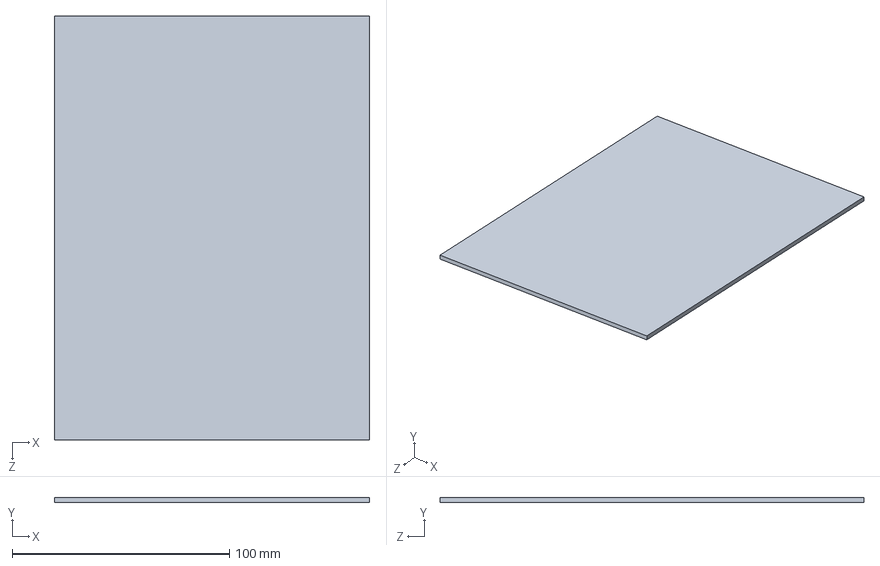
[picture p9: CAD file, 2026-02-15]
CAD/Base Cover.SLDPRT
145.0 x 2.50 x 195.0 mm

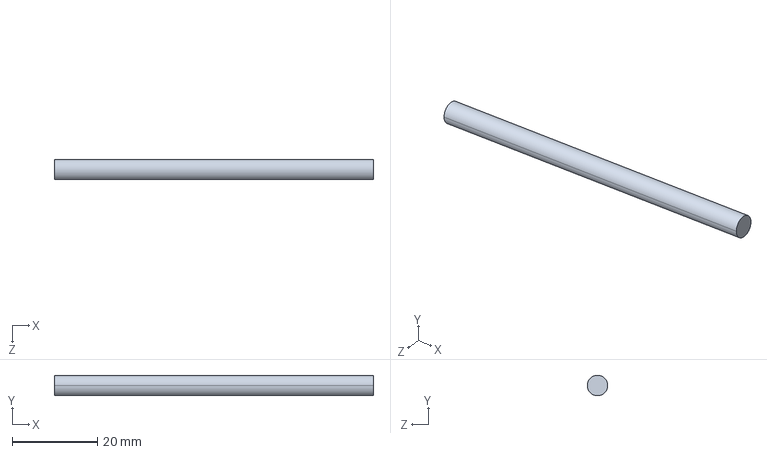
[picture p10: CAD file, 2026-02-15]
CAD/Export/Arm Support Beam.STEP
74.8 x 4.80 x 4.80 mm

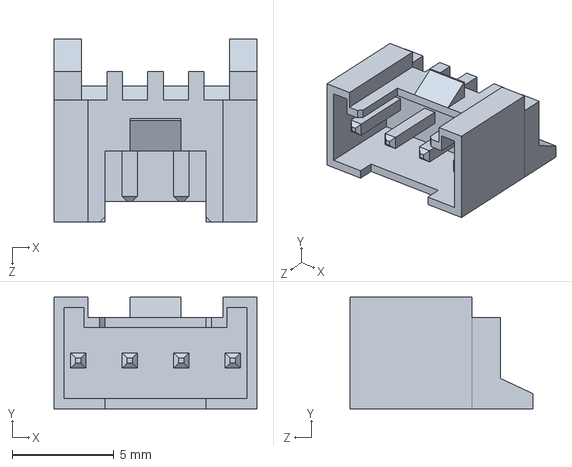
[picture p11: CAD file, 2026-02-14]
CAD/Imported/grove-lcd-rgb-backlight-1.snapshot.6/Grove-LCD RGB Backlight/Connecteur BSG.SLDPRT
10.0 x 5.50 x 9.00 mm

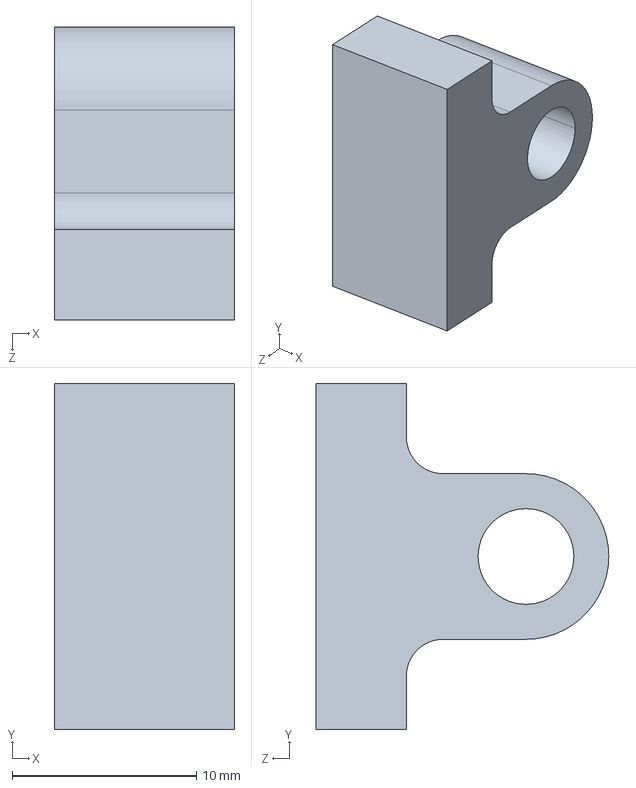
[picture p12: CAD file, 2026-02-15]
CAD/Export/SnapClipAxleHolderSLDPRT.STEP
9.80 x 18.8 x 15.9 mm

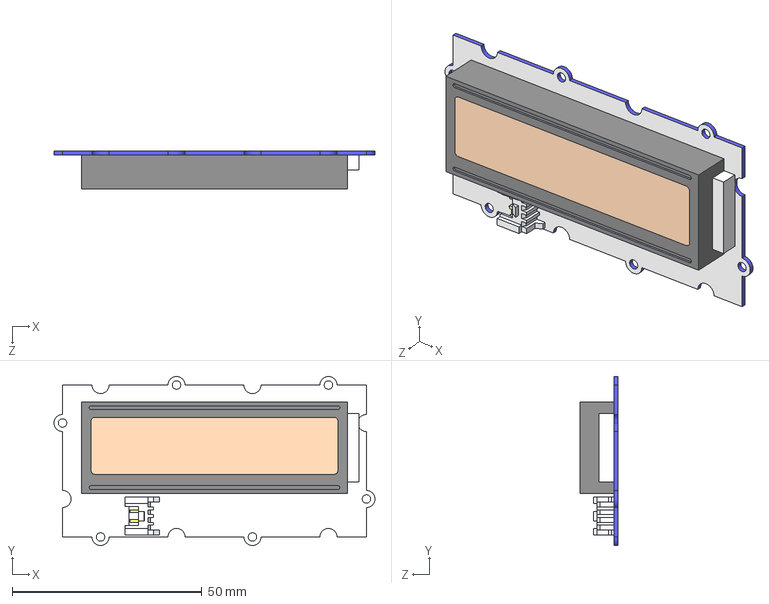
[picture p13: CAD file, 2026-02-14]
CAD/Imported/grove-lcd-rgb-backlight-1.snapshot.6/Grove-LCD RGB Backlight/Grove LCD RGB Backlight.STEP
84.5 x 44.5 x 10.0 mm
LCD RGB Backlight
Connecteur BSG

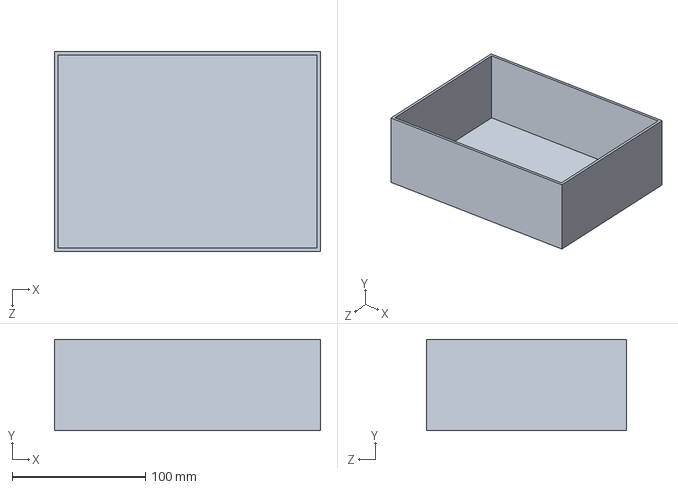
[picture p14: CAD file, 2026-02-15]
CAD/Base.SLDPRT
200.0 x 68.5 x 150.0 mm

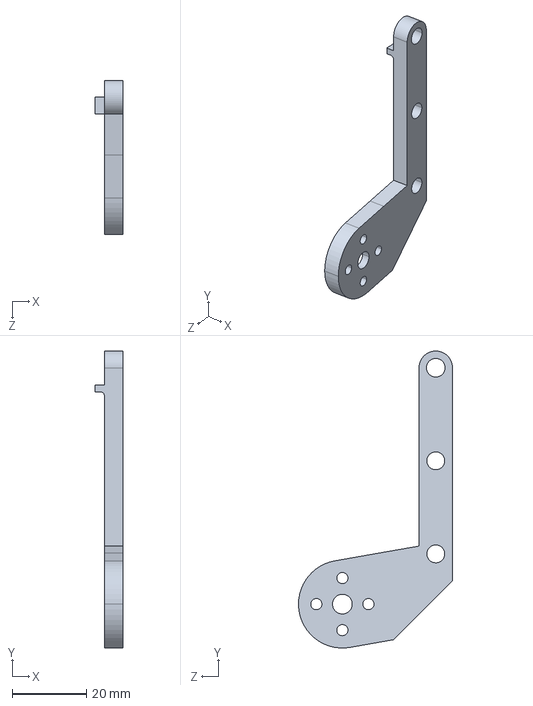
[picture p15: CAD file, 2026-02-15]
CAD/Export/Pivot Arm.STEP
7.50 x 79.8 x 41.4 mm

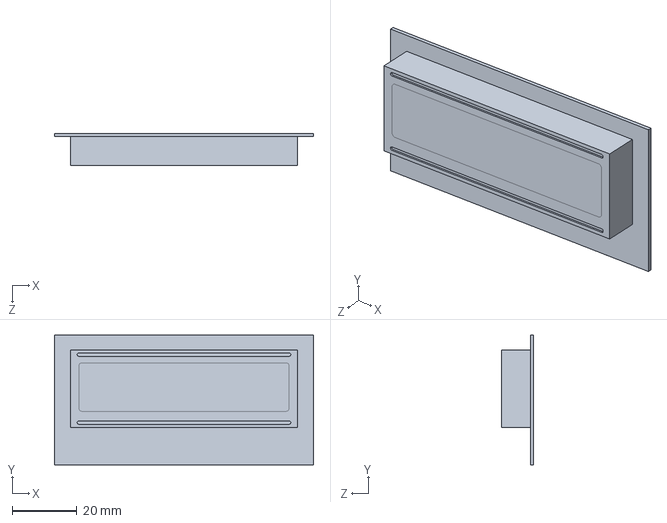
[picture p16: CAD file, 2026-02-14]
CAD/Imported/grove-lcd-rgb-backlight-1.snapshot.6/Grove-LCD RGB Backlight/Plaque de base.SLDPRT
80.0 x 40.0 x 10.0 mm

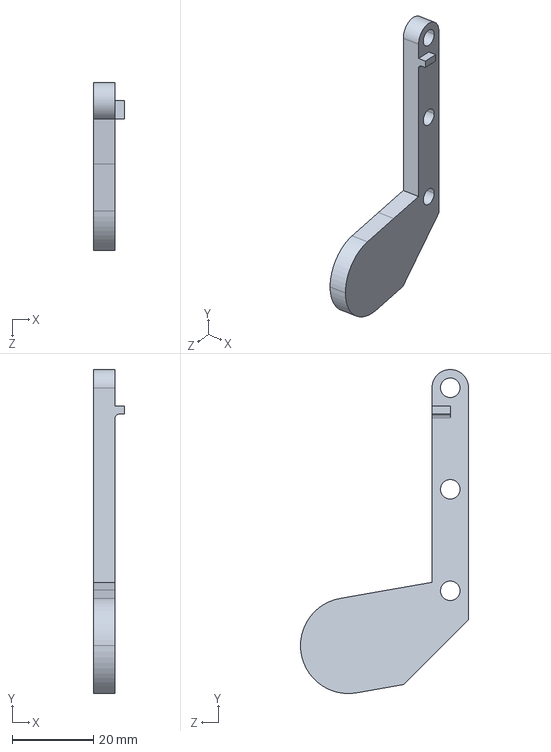
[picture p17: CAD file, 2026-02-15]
CAD/Export/Pivot Arm(non powered).STEP
7.65 x 79.8 x 41.4 mm

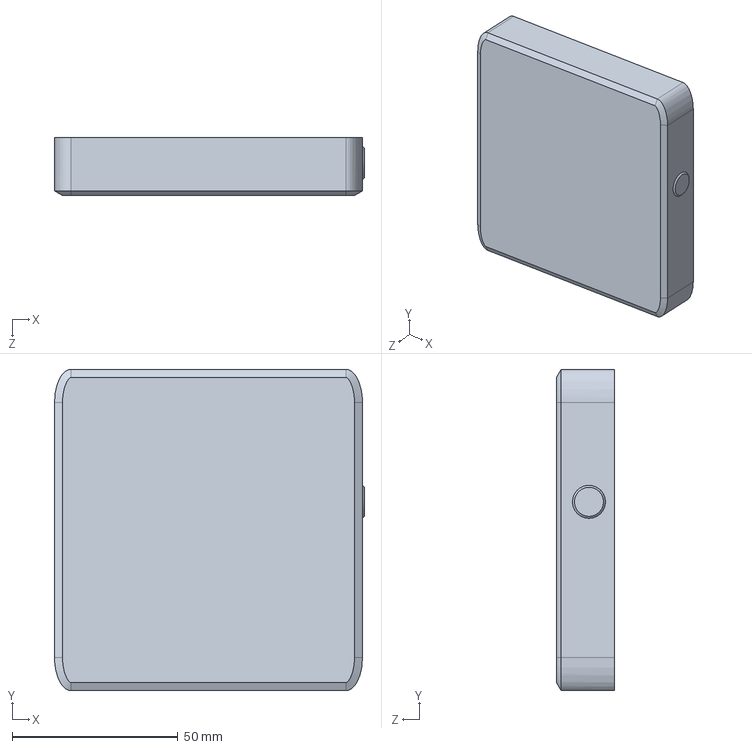
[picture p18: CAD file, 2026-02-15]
CAD/SenseCap Indicator D1.SLDPRT
93.6 x 97.0 x 17.5 mm

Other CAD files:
CAD/Main Assembly.SLDASM
CAD/Imported/td-8135mg-35kg-servo-1.snapshot.2/TD-8135MG Servo.SLDPRT
CAD/Export/Axle.STEP
CAD/Export/3D Print.3mf
CAD/Arm Support Beam.SLDPRT
CAD/Axle.SLDPRT
CAD/Imported/grove-lcd-rgb-backlight-1.snapshot.6/Grove-LCD RGB Backlight/Grove LCD RGB Backlight.SLDASM
CAD/Pivot Arm(non powered).SLDPRT
CAD/Pivot Arm.SLDPRT
CAD/SnapClip.SLDPRT
CAD/SnapClipAxleHolderSLDPRT.SLDPRT

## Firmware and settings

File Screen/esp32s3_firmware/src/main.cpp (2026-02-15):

/*
 * SenseCAP Indicator - Animated Face + Image Display + Touch
 * Main firmware for ESP32-S3
 *
 * Receives JSON commands over CH340 UART (Serial) and/or WiFi TCP socket.
 * Responses and events are sent to BOTH serial and the TCP client (if connected).
 * Binary JPEG data is read from whichever transport sent the image command.
 *
 *   Display modes (mutually exclusive):
 *     {"cmd":"face","on":true/false}          → animated face mode
 *     {"cmd":"image","len":N}                 → JPEG display (disables face)
 *     {"cmd":"clear","color":"#RRGGBB"}       → fill screen with color
 *
 *   Face controls (while face mode is active):
 *     {"cmd":"mouth","open":0.0-1.0}          → mouth openness (lip sync)
 *     {"cmd":"love","value":0.0-1.0}          → love level → floating hearts
 *     {"cmd":"blink"}                         → trigger a manual blink
 *
 *   Audio (via RP2040):
 *     {"cmd":"tone","freq":F,"dur":D}         → buzzer tone
 *     {"cmd":"melody","notes":"..."}          → melody
 *     {"cmd":"stop"}                          → stop buzzer
 *
 *   Hardware:
 *     {"cmd":"bl","on":true/false}            → backlight control
 *
 *   WiFi info:
 *     {"cmd":"wifi"}                          → returns IP/status
 *
 * Emits asynchronous events:
 *     {"event":"touch","x":X,"y":Y}  → touch detected on screen
 *     {"event":"button_down"}         → physical button pressed (GPIO38)
 *     {"event":"button_up"}           → physical button released (GPIO38)
 */

#include <Arduino.h>
#include <ArduinoJson.h>
#include <JPEGDEC.h>
#include "esp_heap_caps.h"
#include "display.h"
#include "pins.h"
#include "face.h"
#include "touch.h"
#include "wifi_link.h"

// ============================================================================
// Constants
// ============================================================================

#define MAX_JPEG_SIZE   (512 * 1024)
#define FRAME_BYTES     (LCD_H_RES * LCD_V_RES * 2)
#define SERIAL_BAUD     921600
#define CMD_BUF_SIZE    512

// Touch debounce: ignore repeated touches for this many ms
#define TOUCH_COOLDOWN_MS  500
static unsigned long s_last_touch_event = 0;

// ============================================================================
// Globals (PSRAM-backed)
// ============================================================================

static uint8_t  *jpeg_buf   = NULL;   // Incoming JPEG data
static uint16_t *decode_buf = NULL;   // Decoded 480x480 RGB565 frame
static JPEGDEC   jpeg;

// WiFi TCP server
static WiFiLink wifi;
static bool s_wifi_ok = false;

// Track which transport sent the current command:
//   0 = Serial (USB), 1 = WiFi TCP
static int s_cmd_source = 0;

// ============================================================================
// Dual Output Helpers (Serial + WiFi)
// ============================================================================

static void dualPrintln(const char* str) {
    Serial.println(str);
    wifi.println(str);
}

static void dualPrintf(const char* fmt, ...) {
    char buf[256];
    va_list args;
    va_start(args, fmt);
    int n = vsnprintf(buf, sizeof(buf), fmt, args);
    va_end(args);
    Serial.write((const uint8_t*)buf, n);
    if (wifi.connected && wifi.client.connected()) {
        wifi.client.write((const uint8_t*)buf, n);
    }
}

// ============================================================================
// JPEG Decode Callback
// ============================================================================

static int jpegDrawCB(JPEGDRAW *pDraw) {
    for (int y = 0; y < pDraw->iHeight; y++) {
        int row = pDraw->y + y;
        if (row >= LCD_V_RES) break;
        int w = pDraw->iWidth;
        if (pDraw->x + w > LCD_H_RES) w = LCD_H_RES - pDraw->x;
        if (pDraw->x < LCD_H_RES && w > 0) {
            memcpy(&decode_buf[row * LCD_H_RES + pDraw->x],
                   &pDraw->pPixels[y * pDraw->iWidth],
                   w * sizeof(uint16_t));
        }
    }
    return 1;
}

// ============================================================================
// RP2040 Communication (buzzer)
// ============================================================================

static void rp2040_tone(int freq, int dur) {
    char buf[64];
    snprintf(buf, sizeof(buf), "TONE %d %d\n", freq, dur);
    Serial1.print(buf);
}

static void rp2040_melody(const char *notes) {
    Serial1.print("MELODY ");
    Serial1.println(notes);
}

static void rp2040_stop() {
    Serial1.println("STOP");
}

// ============================================================================
// Color Helpers
// ============================================================================

static uint16_t hexToRGB565(const char *hex) {
    if (hex[0] == '#') hex++;
    uint32_t rgb = strtoul(hex, NULL, 16);
    uint8_t r = (rgb >> 16) & 0xFF;
    uint8_t g = (rgb >>  8) & 0xFF;
    uint8_t b =  rgb        & 0xFF;
    return ((r >> 3) << 11) | ((g >> 2) << 5) | (b >> 3);
}

// ============================================================================
// Image Handler
// ============================================================================

static void handleImage(uint32_t len) {
    if (len == 0 || len > MAX_JPEG_SIZE) {
        dualPrintf("{\"status\":\"error\",\"msg\":\"bad len %u\"}\n", len);
        return;
    }

    // Signal ready
    dualPrintln("{\"status\":\"ready\"}");
    Serial.flush();
    wifi.flush();

    // Receive raw JPEG bytes from whichever transport sent the command
    uint32_t received = 0;
    unsigned long deadline = millis() + 30000;

    if (s_cmd_source == 1) {
        // WiFi TCP source
        while (received < len && millis() < deadline) {
            int avail = wifi.availableBytes();
            if (avail > 0) {
                uint32_t want = len - received;
                if ((uint32_t)avail < want) want = avail;
                size_t got = wifi.readBytes(jpeg_buf + received, want);
                received += got;
                if (got > 0) deadline = millis() + 5000;
            }
            yield();
        }
    } else {
        // Serial USB source
        while (received < len && millis() < deadline) {
            int avail = Serial.available();
            if (avail > 0) {
                uint32_t want = len - received;
                if ((uint32_t)avail < want) want = avail;
                size_t got = Serial.readBytes(jpeg_buf + received, want);
                received += got;
                if (got > 0) deadline = millis() + 5000;
            }
            yield();
        }
    }

    if (received != len) {
        dualPrintf("{\"status\":\"error\",\"msg\":\"got %u/%u\"}\n", received, len);
        return;
    }

    // Decode JPEG to RGB565
    if (!jpeg.openRAM(jpeg_buf, len, jpegDrawCB)) {
        dualPrintln("{\"status\":\"error\",\"msg\":\"jpeg open fail\"}");
        return;
    }
    jpeg.setPixelType(RGB565_LITTLE_ENDIAN);
    memset(decode_buf, 0, FRAME_BYTES);

    if (!jpeg.decode(0, 0, 0)) {
        dualPrintln("{\"status\":\"error\",\"msg\":\"jpeg decode fail\"}");
        jpeg.close();
        return;
    }
    jpeg.close();

    // Push to display
    display_draw_fullscreen(decode_buf);
    dualPrintln("{\"status\":\"ok\"}");
}

// ============================================================================
// Command Dispatcher
// ============================================================================

static void handleCommand(const char *line) {
    StaticJsonDocument<256> doc;
    if (deserializeJson(doc, line)) {
        dualPrintln("{\"status\":\"error\",\"msg\":\"bad json\"}");
        return;
    }

    const char *cmd = doc["cmd"];
    if (!cmd) {
        dualPrintln("{\"status\":\"error\",\"msg\":\"no cmd\"}");
        return;
    }

    if (strcmp(cmd, "image") == 0) {
        face_set_enabled(false);  // Image mode takes over from face
        handleImage(doc["len"] | (uint32_t)0);
    }
    else if (strcmp(cmd, "clear") == 0) {
        display_fill(hexToRGB565(doc["color"] | "#000000"));
        dualPrintln("{\"status\":\"ok\"}");
    }
    else if (strcmp(cmd, "tone") == 0) {
        rp2040_tone(doc["freq"] | 1000, doc["dur"] | 200);
        dualPrintln("{\"status\":\"ok\"}");
    }
    else if (strcmp(cmd, "melody") == 0) {
        rp2040_melody(doc["notes"] | "");
        dualPrintln("{\"status\":\"ok\"}");
    }
    else if (strcmp(cmd, "stop") == 0) {
        rp2040_stop();
        dualPrintln("{\"status\":\"ok\"}");
    }
    else if (strcmp(cmd, "bl") == 0) {
        display_backlight(doc["on"] | true);
        dualPrintln("{\"status\":\"ok\"}");
    }
    // ---- WiFi info ----
    else if (strcmp(cmd, "wifi") == 0) {
        if (s_wifi_ok) {
            dualPrintf("{\"status\":\"ok\",\"ip\":\"%s\",\"port\":%d}\n",
                       wifi.ipAddress().c_str(), TCP_PORT);
        } else {
            dualPrintln("{\"status\":\"ok\",\"ip\":\"none\",\"msg\":\"wifi not connected\"}");
        }
    }
    // ---- Face mode commands ----
    else if (strcmp(cmd, "face") == 0) {
        bool on = doc["on"] | false;
        face_set_enabled(on);
        if (!on) display_fill(0x0000);  // Clear to black when leaving face mode
        dualPrintln("{\"status\":\"ok\"}");
    }
    else if (strcmp(cmd, "mouth") == 0) {
        face_set_mouth(doc["open"] | 0.0f);
        dualPrintln("{\"status\":\"ok\"}");
    }
    else if (strcmp(cmd, "love") == 0) {
        face_set_love(doc["value"] | 0.0f);
        dualPrintln("{\"status\":\"ok\"}");
    }
    else if (strcmp(cmd, "blink") == 0) {
        face_blink();
        dualPrintln("{\"status\":\"ok\"}");
    }
    else {
        dualPrintln("{\"status\":\"error\",\"msg\":\"unknown cmd\"}");
    }
}

// ============================================================================
// Arduino Entry Points
// ============================================================================

void setup() {
    Serial.setRxBufferSize(4096);
    Serial.begin(SERIAL_BAUD);
    delay(500);

    // Internal UART to RP2040 (buzzer control)
    Serial1.begin(UART_RP2040_BAUD, SERIAL_8N1, PIN_UART_RP2040_RX, PIN_UART_RP2040_TX);

    Serial.println("{\"status\":\"booting\"}");

    // Connect WiFi and start TCP server
    s_wifi_ok = wifi.begin();
    if (s_wifi_ok) {
        Serial.printf("{\"status\":\"wifi\",\"ip\":\"%s\",\"port\":%d}\n",
                      wifi.ipAddress().c_str(), TCP_PORT);
    }

    // Allocate PSRAM buffers
    jpeg_buf   = (uint8_t  *)heap_caps_malloc(MAX_JPEG_SIZE, MALLOC_CAP_SPIRAM);
    decode_buf = (uint16_t *)heap_caps_malloc(FRAME_BYTES,   MALLOC_CAP_SPIRAM);
    if (!jpeg_buf || !decode_buf) {
        Serial.println("{\"status\":\"error\",\"msg\":\"PSRAM alloc failed\"}");
        return;
    }

    // Initialize display hardware
    if (!display_init()) {
        Serial.println("{\"status\":\"error\",\"msg\":\"display init failed\"}");
        return;
    }

    // Initialize face renderer
    if (!face_init()) {
        Serial.println("{\"status\":\"warning\",\"msg\":\"face init failed (PSRAM?)\"}");
    } else {
        face_set_enabled(true);  // Start in face mode by default
    }

    // Initialize touch controller (FT6336U) + physical button
    if (touch_init()) {
        Serial.println("{\"status\":\"info\",\"msg\":\"touch ready\"}");
    }
    button_init();

    dualPrintln("{\"status\":\"ready\"}");
}

void loop() {
    // --- Poll WiFi TCP server ---
    if (s_wifi_ok) {
        wifi.poll();
    }

    // --- Check USB serial ---
    if (Serial.available()) {
        s_cmd_source = 0;
        String line = Serial.readStringUntil('\n');
        line.trim();
        if (line.length() > 0) {
            handleCommand(line.c_str());
        }
    }

    // --- Check WiFi TCP ---
    if (s_wifi_ok && wifi.available()) {
        String line = wifi.readLine();
        if (line.length() > 0) {
            s_cmd_source = 1;
            handleCommand(line.c_str());
        }
    }

    // --- Touch / button event detection ---
    unsigned long now = millis();

    // Poll capacitive touch
    TouchPoint tp = touch_read();
    if (tp.touched && (now - s_last_touch_event) > TOUCH_COOLDOWN_MS) {
        s_last_touch_event = now;
        dualPrintf("{\"event\":\"touch\",\"x\":%d,\"y\":%d}\n", tp.x, tp.y);
        rp2040_tone(1500, 60);
    }

    // Poll physical user button (GPIO38) — emit down/up events
    int btn = button_edge();
    if (btn == 1) {
        dualPrintln("{\"event\":\"button_down\"}");
        rp2040_tone(1000, 60);
    } else if (btn == -1) {
        dualPrintln("{\"event\":\"button_up\"}");
        rp2040_tone(800, 40);
    }

    // Render face animation (rate-limited internally)
    if (face_is_enabled()) {
        face_update();
    } else {
        delay(1);
    }
}

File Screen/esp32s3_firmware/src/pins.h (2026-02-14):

/*
 * Pin definitions for SenseCAP Indicator D1101
 * ESP32-S3 GPIO assignments
 *
 * Source: Official Seeed SenseCAP_Indicator_ESP32 SDK
 * (components/bsp/src/boards/sensecap_indicator_board.c)
 */

#pragma once

// ============================================================================
// I2C Bus (shared: IO expander TCA9535 + touch panel)
// ============================================================================
#define PIN_I2C_SDA       39
#define PIN_I2C_SCL       40

// ============================================================================
// TCA9535 IO Expander (I2C address 0x20)
// Pins on the expander used for LCD control:
//   Pin 4 = LCD CS (active low)
//   Pin 5 = LCD RESET (active low reset)
//   Pin 7 = Touch Panel RESET
// ============================================================================
#define TCA9535_ADDR      0x20
#define EXPANDER_LCD_CS   4
#define EXPANDER_LCD_RST  5
#define EXPANDER_TP_RST   7

// ============================================================================
// LCD - 3-Wire SPI (for ST7701S initialization, bit-banged GPIOs)
// CS and RESET go through the TCA9535 IO expander (I2C).
// CLK and MOSI are direct ESP32-S3 GPIOs.
// ============================================================================
#define PIN_LCD_SPI_CLK   41    // GPIO bit-bang SPI clock
#define PIN_LCD_SPI_MOSI  48    // GPIO bit-bang SPI data

// ============================================================================
// LCD - RGB Parallel Interface (16-bit, RGB565)
// Pin mapping from official SDK board description
// ============================================================================
#define PIN_LCD_VSYNC     17
#define PIN_LCD_HSYNC     16
#define PIN_LCD_DE        18
#define PIN_LCD_PCLK      21
#define PIN_LCD_BL        45    // Backlight enable
#define LCD_BL_ON_LEVEL   1

// RGB data pins: DATA0..15  →  B[4:0], G[5:0], R[4:0]
#define PIN_LCD_D0        15    // B0
#define PIN_LCD_D1        14    // B1
#define PIN_LCD_D2        13    // B2
#define PIN_LCD_D3        12    // B3
#define PIN_LCD_D4        11    // B4
#define PIN_LCD_D5        10    // G0
#define PIN_LCD_D6         9    // G1
#define PIN_LCD_D7         8    // G2
#define PIN_LCD_D8         7    // G3
#define PIN_LCD_D9         6    // G4
#define PIN_LCD_D10        5    // G5
#define PIN_LCD_D11        4    // R0
#define PIN_LCD_D12        3    // R1
#define PIN_LCD_D13        2    // R2
#define PIN_LCD_D14        1    // R3
#define PIN_LCD_D15        0    // R4

// ============================================================================
// LCD Display Parameters
// ============================================================================
#define LCD_H_RES         480
#define LCD_V_RES         480
#define LCD_PIXEL_CLK_HZ  (18 * 1000 * 1000)   // 18 MHz pixel clock

// RGB timing parameters (from official SDK)
#define LCD_HSYNC_BACK_PORCH    50
#define LCD_HSYNC_FRONT_PORCH   10
#define LCD_HSYNC_PULSE_WIDTH    8
#define LCD_VSYNC_BACK_PORCH    20
#define LCD_VSYNC_FRONT_PORCH   10
#define LCD_VSYNC_PULSE_WIDTH    8
#define LCD_PCLK_ACTIVE_NEG      0   // Data sampled on rising edge

// ============================================================================
// Internal UART (ESP32-S3 <-> RP2040)
// ============================================================================
#define PIN_UART_RP2040_TX  19  // ESP32-S3 TX -> RP2040 RX
#define PIN_UART_RP2040_RX  20  // ESP32-S3 RX <- RP2040 TX
#define UART_RP2040_BAUD    115200

// ============================================================================
// User Button
// ============================================================================
#define PIN_BUTTON_USER   38

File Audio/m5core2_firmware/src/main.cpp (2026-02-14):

/*
 * M5Stack Core Audio Streaming Firmware
 *
 * Connects to WiFi, runs a simple HTTP control API.
 * The Raspberry Pi tells the M5Core2 to play audio from a URL
 * (typically an MP3 served by the Pi's audio server).
 *
 * HTTP API (M5Core2 listens on port 8082):
 *   POST /play   body: {"url":"http://pi:8080/audio/latest.mp3"}
 *   POST /stop
 *   POST /volume body: {"level":5}  (0-10)
 *   GET  /status
 *
 * Audio path:
 *   HTTP URL → ESP8266Audio ICY Stream → MP3 Decoder → I2S → Speaker
 *
 * Core1 audio output uses INTERNAL_DAC (GPIO25/26)
 */

#include <M5Stack.h>
#include <driver/i2s.h>
#include <WiFi.h>
#include <WebServer.h>
#include <ArduinoJson.h>

#include <AudioFileSourceHTTPStream.h>
#include <AudioFileSourceBuffer.h>
#include <AudioGeneratorMP3.h>
#include <AudioGeneratorWAV.h>
#include <AudioOutputI2S.h>

#include "wifi_config.h"

// ============================================================================
// Audio objects
// ============================================================================

static AudioGeneratorMP3        *mp3       = nullptr;
static AudioGeneratorWAV        *wav       = nullptr;
static AudioFileSourceHTTPStream *httpSrc   = nullptr;
static AudioFileSourceBuffer    *bufSrc    = nullptr;
static AudioOutputI2S           *audioOut  = nullptr;

// Stream buffer (Core1 has less RAM than Core2)
static const int BUF_SIZE = 64 * 1024;
static void *preallocateBuffer = nullptr;

static float gainLevel = 0.3;  // matching working repo default
static const float gainFactor = 0.08;  // from working repo
static bool  isPlaying = false;
static String currentUrl = "";
static String playFormat = "mp3";  // "mp3" or "wav"

// Deferred play: HTTP handler sets these, loop() picks them up
static String pendingUrl = "";
static String pendingFmt = "";
static bool  pendingPlay = false;

// ============================================================================
// HTTP control server
// ============================================================================

static WebServer server(HTTP_PORT);

// ============================================================================
// Display helpers
// ============================================================================

static void lcd(const char *line1, const char *line2 = "", uint16_t color = TFT_WHITE) {
    M5.Lcd.fillScreen(TFT_BLACK);
    M5.Lcd.setTextColor(color, TFT_BLACK);
    M5.Lcd.setTextDatum(MC_DATUM);
    M5.Lcd.setTextSize(2);
    M5.Lcd.drawString(line1, 160, 100);
    M5.Lcd.setTextSize(1);
    M5.Lcd.drawString(line2, 160, 140);
}

static void lcdStatus() {
    M5.Lcd.fillScreen(TFT_BLACK);
    M5.Lcd.setTextColor(TFT_GREEN, TFT_BLACK);
    M5.Lcd.setTextDatum(TC_DATUM);
    M5.Lcd.setTextSize(2);
    M5.Lcd.drawString("Audio Player", 160, 10);
    M5.Lcd.setTextSize(1);
    M5.Lcd.setTextColor(TFT_WHITE, TFT_BLACK);
    M5.Lcd.drawString("IP: " + WiFi.localIP().toString(), 160, 50);
    M5.Lcd.drawString("Port: " + String(HTTP_PORT), 160, 70);
    M5.Lcd.drawString(isPlaying ? "Playing..." : "Idle", 160, 100);
    M5.Lcd.drawString("Vol: " + String((int)(gainLevel * 10)), 160, 120);
    if (currentUrl.length() > 0) {
        String shortUrl = currentUrl;
        if (shortUrl.length() > 40) shortUrl = shortUrl.substring(0, 40) + "...";
        M5.Lcd.drawString(shortUrl, 160, 150);
    }
}

// ============================================================================
// Audio control
// ============================================================================

static void stopAudio() {
    if (mp3) { mp3->stop(); delete mp3; mp3 = nullptr; }
    if (wav) { wav->stop(); delete wav; wav = nullptr; }
    if (bufSrc) { bufSrc->close(); delete bufSrc; bufSrc = nullptr; }
    if (httpSrc) { httpSrc->close(); delete httpSrc; httpSrc = nullptr; }
    if (audioOut) { delete audioOut; audioOut = nullptr; }
    isPlaying = false;
    Serial.println("Audio stopped");
    lcdStatus();
}

static bool startAudio(const String &url, const String &fmt) {
    stopAudio();

    Serial.printf("Playing: %s (format: %s)\n", url.c_str(), fmt.c_str());
    currentUrl = url;
    playFormat = fmt;

    // Create I2S output using internal DAC (Core1 speaker path)
    audioOut = new AudioOutputI2S(0, AudioOutputI2S::INTERNAL_DAC);
    audioOut->SetOutputModeMono(true);
    audioOut->SetGain(gainLevel);
    Serial.printf("I2S output created (gain=%.2f)\n", gainLevel);

    // Create HTTP source
    Serial.printf("Connecting to stream: %s\n", url.c_str());
    httpSrc = new AudioFileSourceHTTPStream(url.c_str());
    if (!httpSrc) {
        Serial.println("ERROR: Failed to create HTTP source");
        stopAudio();
        return false;
    }
    Serial.println("HTTP source created");

    // Buffer with pre-allocated memory (matching working repo pattern)
    bufSrc = new AudioFileSourceBuffer(httpSrc, preallocateBuffer, BUF_SIZE);
    Serial.println("Buffer source created");

    bool ok = false;
    if (fmt == "wav") {
        wav = new AudioGeneratorWAV();
        ok = wav->begin(bufSrc, audioOut);
        Serial.printf("WAV begin: %s\n", ok ? "OK" : "FAIL");
    } else {
        // Default to MP3
        mp3 = new AudioGeneratorMP3();
        ok = mp3->begin(bufSrc, audioOut);
        Serial.printf("MP3 begin: %s\n", ok ? "OK" : "FAIL");
    }

    if (!ok) {
        Serial.println("ERROR: Failed to start audio playback");
        stopAudio();
        return false;
    }

    isPlaying = true;
    lcd("Playing", url.c_str(), TFT_GREEN);
    return true;
}

// ============================================================================
// HTTP route handlers
// ============================================================================

static void handlePlay() {
    if (!server.hasArg("plain")) {
        server.send(400, "application/json", "{\"error\":\"no body\"}");
        return;
    }
    StaticJsonDocument<512> doc;
    if (deserializeJson(doc, server.arg("plain"))) {
        server.send(400, "application/json", "{\"error\":\"bad json\"}");
        return;
    }
    const char *url = doc["url"];
    if (!url) {
        server.send(400, "application/json", "{\"error\":\"no url\"}");
        return;
    }
    String fmt = doc["format"] | "mp3";
    // Defer actual playback to loop() so HTTP responds immediately
    pendingUrl = String(url);
    pendingFmt = fmt;
    pendingPlay = true;
    server.send(200, "application/json", "{\"status\":\"queued\"}");
}

static void handleStop() {
    stopAudio();
    server.send(200, "application/json", "{\"status\":\"stopped\"}");
}
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

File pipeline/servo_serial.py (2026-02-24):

"""
Servo Serial — Talk to the ESP32 servo controller over USB serial.

The ESP32 accepts two commands:
    S<angle>        Set servo angle (0 to 270)
    C<r>,<g>,<b>    Set LCD backlight colour

This module maps an interest level (0–10) to:
    - Love value for SenseCAP screen (0.0 – 1.0)
    - Servo angle for the arm (120 – 150)
        - Servo angle for the arm (120 – 150)

Usage:
    servo = ServoSerial("/dev/ttyUSB0")     # or "COM7", etc.
    servo.set_interest(7.5)                 # drives servo + returns love value
    servo.close()
"""

import serial
import time

# Servo angle range that maps to interest 0..10
SERVO_MIN = 120
SERVO_MAX = 150


class ServoSerial:
    """Persistent serial connection to the ESP32 servo board."""

    def __init__(self, port: str, baud: int = 115200, timeout: float = 1.0, init_angle: int = 135):
        self.port = port
        self.ser = serial.Serial(port, baud, timeout=timeout)
        time.sleep(0.5)  # Let ESP32 finish boot
        # Drain any boot messages
        while self.ser.in_waiting:
            self.ser.read(self.ser.in_waiting)
        print(f"  [servo] Connected to {port}")
        # Initialize servo to a known starting angle.
        self.send_servo(init_angle)
        print(f"  [servo] Init angle S{int(init_angle)}")

    # ------------------------------------------------------------------
    # Low-level commands
    # ------------------------------------------------------------------

    def send_servo(self, angle: int):
        """Send an S<angle> command (clamped to SERVO_MIN–SERVO_MAX)."""
        angle = max(SERVO_MIN, min(SERVO_MAX, int(angle)))
        cmd = f"S{angle}\n"
        self.ser.write(cmd.encode())
        self.ser.flush()

    def send_color(self, r: int, g: int, b: int):
        """Send a C<r>,<g>,<b> command."""
        cmd = f"C{r},{g},{b}\n"
        self.ser.write(cmd.encode())
        self.ser.flush()

    # ------------------------------------------------------------------
    # High-level helpers
    # ------------------------------------------------------------------

    @staticmethod
    def interest_to_love(interest: float) -> float:
        """Map interest (0–10) → love value (0.0–1.0)."""
        return max(0.0, min(1.0, interest / 10.0))

    @staticmethod
    def interest_to_servo(interest: float) -> int:
        """Map interest (0–10) → servo angle (SERVO_MIN–SERVO_MAX)."""
        t = max(0.0, min(10.0, interest)) / 10.0
        return int(SERVO_MIN + t * (SERVO_MAX - SERVO_MIN))

    def set_interest(self, interest: float) -> float:
        """Apply interest (0–10) to servo and return love value (0.0–1.0)."""
        angle = self.interest_to_servo(float(interest))
        self.send_servo(angle)
        print(f"  [servo] interest={interest} -> angle={angle}")
        return self.interest_to_love(float(interest))

    # ------------------------------------------------------------------

    def close(self):
        if self.ser and self.ser.is_open:
            self.ser.close()
            print(f"  [servo] Closed {self.port}")

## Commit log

2026-02-14 Add display (SenseCAP ESP32-S3 + RP2040) and audio (M5Stack Core1) with streaming pipeline
    - SenseCAP Indicator D1101: JPEG image display via serial (COM6, 921600 baud)
    * ESP32-S3 firmware with TCA9535 IO expander, ST7701S LCD init, JPEGDEC decoder
    * RP2040 firmware with buzzer on GP19
    * Python controller with image resizing via Pillow
    - M5Stack Core (gen1): WiFi HTTP audio player with internal DAC speaker output
    * Retargeted from Core2 to Core1 hardware (M5Stack v0.4.6 library)
    * WiFi control API: /play, /stop, /volume, /status, /tone endpoints
    * ESP8266Audio MP3/WAV streaming with 64KB buffer
    * Deferred playback pattern for non-blocking HTTP responses
    - Pipeline: Python Fla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
    [audio_server.py, display.cpp, lcd_init.cpp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]
2026-02-14 initalized the design for the "robot"
    [Base.SLDPRT]
2026-02-14 Imported LCD display
    [Connecteur BSG.SLDPRT, Grove LCD RGB Backlight.SLDASM, Grove LCD RGB Backlight.STEP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]
2026-02-14 feat: Add animated face renderer and touch driver for SenseCAP Indicator
    - Implemented face.cpp and face.h for rendering an animated face with floating eyes, blinking, and a controllable mouth.
    - Added touch.cpp and touch.h for capacitive touch driver supporting FT6336U and CST816S controllers, including a physical button fallback.
    - Created date_pipeline.py to stream webcam video to the SenseCAP display with a "Date" button overlay, capturing frames on button press.
    - Introduced test_touch.py for monitoring serial output and touch events from the SenseCAP.
2026-02-14 v1 of esp32 code for servo and LED
2026-02-14 Bunch oh cad
    [Arm.SLDPRT, Base.SLDPRT, Main Assembly.SLDASM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]
2026-02-14 added imported cad, added some arm stuff, axle
    [Arm.SLDPRT, Main Assembly.SLDASM, Pivot Arm.SLDPRT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]
2026-02-14 Add conversation pipeline for push-to-talk functionality with webcam mic
    - Implemented PushToTalkRecorder class for audio recording while button is held
    - Integrated SpeechRecognition for transcribing recorded audio to text
    - Established communication with Node.js server for personality generation and response handling
    - Created a conversation loop that manages recording, transcription, and AI responses
    - Added CLI entry point for standalone testing and configuration options
    - Included device detection for external webcam microphones
2026-02-14 Add migration plan for transitioning Object-Love-Interface to Raspberry Pi
2026-02-15 Massive cad update
    [3D Print.3mf, Arm Support Beam.SLDPRT, Arm Support Beam.STEP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]
2026-02-15 Refactor WiFi communication and enhance testing suite
    - Fix typo in interest loading from JSON
    - Update interest value in interest.json
    - Modify personality.json to change character identity
    - Change voiceId in voice.json
    - Improve camera probing logic in date_pipeline.py
    - Enhance mouth sync functionality in mouth_sync.py
    - Add send_raw_line method to WiFiLink class
    - Create test_backends.py for backend verification
    - Add test_love.py for sending love value over WiFi
    - Implement test_wifi.py for WiFiLink communication tests
    - Develop test_wifi_image.py for JPEG image transfer over WiFi
    [date_pipeline.py, mouth_sync.py, wifi_link.py]
2026-02-15 Add script to identify USB cameras on Raspberry Pi
2026-02-15 Add camera detection script for Raspberry Pi with USB support
2026-02-15 Enhance camera selection in date_pipeline.py to support device paths and string indices
2026-02-15 Add servo control and interest handling to conversation pipeline
    - Introduced ServoSerial class for ESP32 servo communication.
    - Updated conversation.py to manage interest levels and servo angles.
    - Enhanced date_pipeline.py to initialize and pass servo instance.
    - Modified index.js to include interest in response payload.
2026-02-15 Add WiFi TCP communication between RPi and SenseCAP
    ESP32-S3 firmware:
    - WiFi STA + TCP server on port 7777 with mDNS (sensecap.local)
    - Accepts JSON commands and JPEG binary over TCP (same protocol as serial)
    - Dual output: responses/events sent to both USB serial AND WiFi client
    - handleImage reads JPEG from whichever transport sent the command
    - New 'wifi' command returns IP/port info
    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
2026-02-15 Refine servo control logic and add configuration checks in conversation and date pipelines
2026-02-15 Update initial interest value to 0 and adjust servo angle clamping logic
2026-02-15 modified: pipeline/servo_serial.py
2026-02-15 Update servo angle mapping and clamping logic in ServoSerial class
2026-02-15 Add error handling for microphone sample rate in PushToTalkRecorder
    [conversation.py]
2026-02-15 Add demo script and implement GPIO reset button functionality
    - Introduced a demo script for the Object Love Interface hackathon.
    - Added GPIO reset button support to allow for graceful reset of the pipeline.
    - Enhanced conversation and date pipeline to handle reset requests.
    [conversation.py, date_pipeline.py, gpio_button.py]
2026-02-15 Add limit switch functionality to GPIO handling in date_pipeline and gpio_button
2026-02-15 Refactor GpioLimitSwitch to use interrupt-based edge detection and improve state handling
2026-02-15 Add limit switch restart functionality to the pipeline
2026-02-15 Refactor limit switch restart handling in the pipeline
